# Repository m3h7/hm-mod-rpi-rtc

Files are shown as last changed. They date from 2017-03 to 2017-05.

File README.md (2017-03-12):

# hm-mod-rpi-rtc
Copyright (c) 2017 Maik Hinrichs  
**License**: [Creative Commons Attribution 4.0 International (CC BY-NC-SA 4.0)](https://creativecommons.org/licenses/by-nc-sa/4.0/).

Ergänzung des Homematic Funkmodules [hm-mod-rpi-pcb](https://www.elv.de/homematic-funkmodul-fuer-raspberry-pi-bausatz.html)
für den Raspberry Pi um eine Real Time Clock (RTC).

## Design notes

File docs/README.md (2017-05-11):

# hm-mod-rpi-rtc
## Schaltplan
[Schaltplan des Modules](hm-mod-rpi-rtc.pdf "Schaltplan")
## Bestückungsplan
- Vorderseite

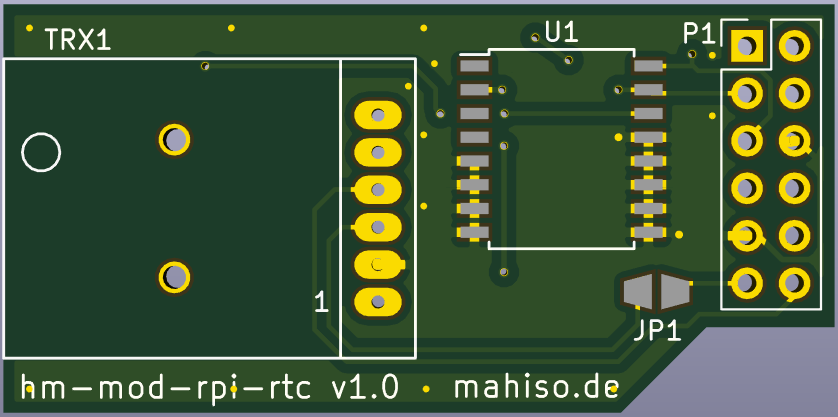
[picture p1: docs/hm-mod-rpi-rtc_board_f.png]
Bestückungsplan Vorderseite


- Rückseite

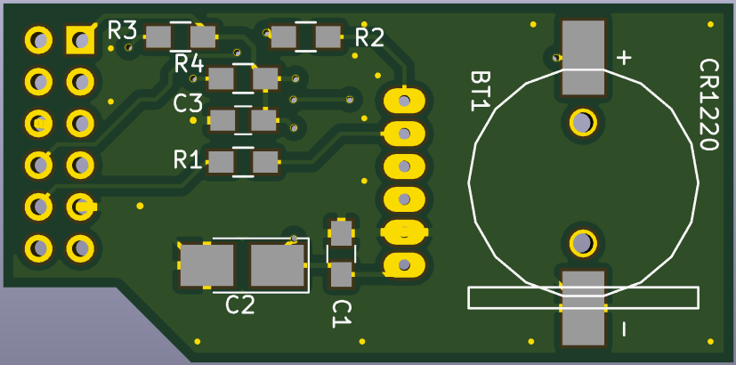
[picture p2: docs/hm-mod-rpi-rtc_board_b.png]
Bestückungsplan Rückseite


**Anmerkung**: Bestückungszeichnung der Batteriehalterung BT1 ist falsch. Eingesetzt (siehe untere Ansicht) ist die Halterung korrekt (Issue #3)

## Stückliste
|Bezeichnung|Wert / Bauform|Anmerkung|Reichelt Nr.|
|---|---|---|---|
|TRX1|HM-MOD-UART|aus ELV Bausatz|-|
|P1|Buchsenleiste 2x6|aus ELV Bausatz|-|
|U1|DS3231 / SOIC-16W ||DS 3231 S|
|R1,R2|1kΩ / 0805||RND 0805 1 1,0K
|R3,R4|4.7kΩ / 0805||RND 0805 1 4,7K|
|C1,C3|100nF / 0805||X7R-G0805 100N|
|C2|100µF/10V / Tantal B||TAJ 3528 100/10|
|BT1|Batteriehalter CR1220||-|
|CR1220|Batterie CR1220||CR 1220|

* Reichelt Bestellnummern ohne Garantie.

## Ansichten
- Bestückte Vorderseite

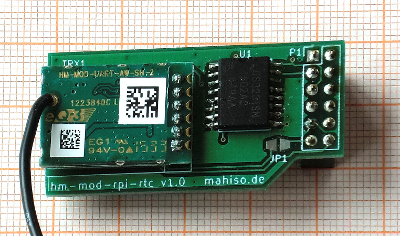
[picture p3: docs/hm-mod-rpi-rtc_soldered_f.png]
Bestückte Vorderseite

- Bestückte Rückseite

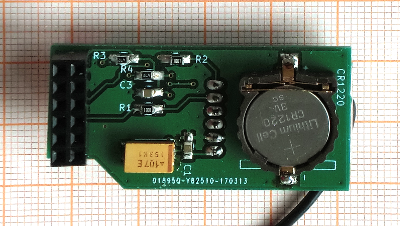
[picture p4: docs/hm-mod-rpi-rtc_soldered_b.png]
Bestückte Rückseite

- Eingesetzt in Raspberry Pi 2

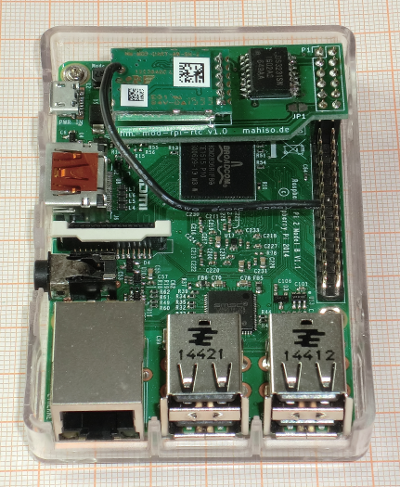
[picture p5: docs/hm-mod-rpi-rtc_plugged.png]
Eingesetzt in Raspberry Pi 2


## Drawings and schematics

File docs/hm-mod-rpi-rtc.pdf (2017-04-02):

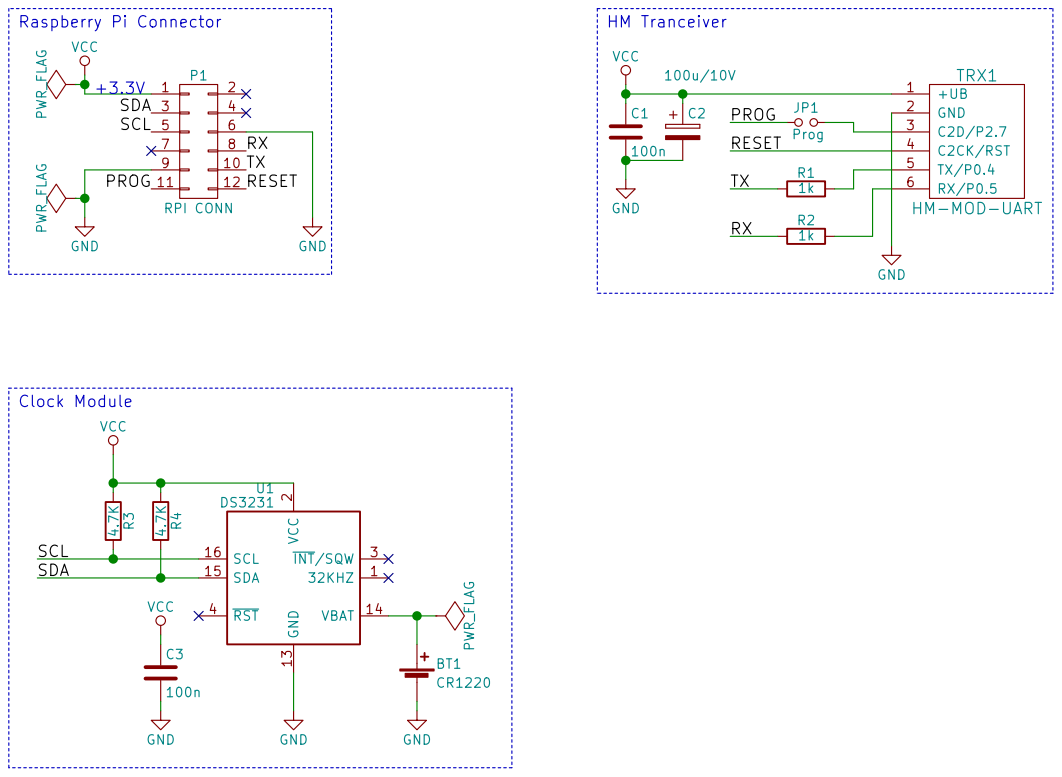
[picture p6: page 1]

File: hm-mod-rpi-rtc.sch Sheet: / M. Hinrichs

Id: 1/1 Title: HM-MOD-RPI-RTC

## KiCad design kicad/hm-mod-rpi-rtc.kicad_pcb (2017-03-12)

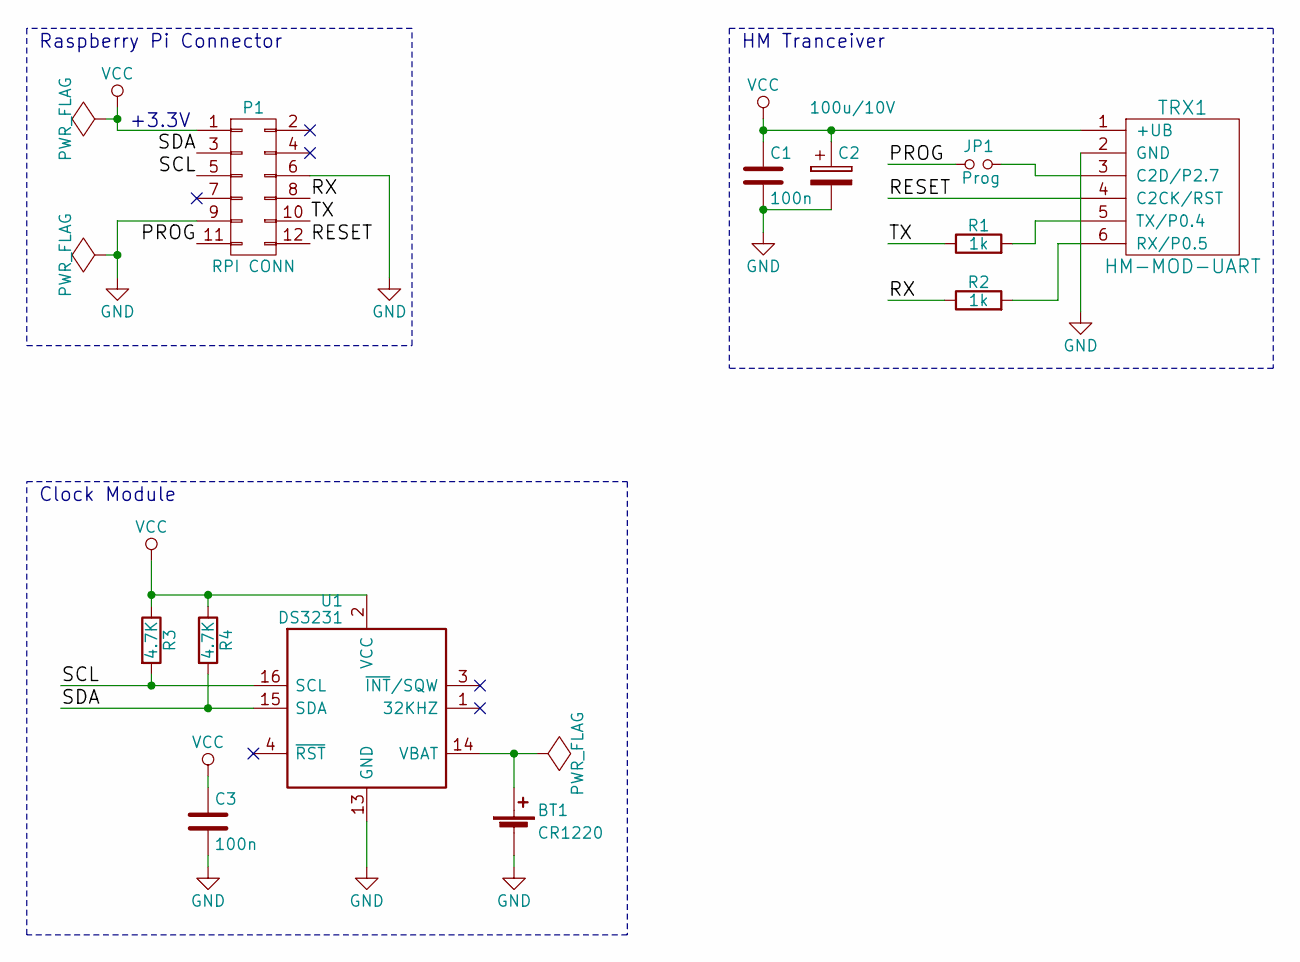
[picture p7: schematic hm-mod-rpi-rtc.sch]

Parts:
BT1: CR1220; CR1220_holder
C1, C3: 100n; C_0805_HandSoldering
C2: 100u/10V; CP_Tantalum_Case-B_EIA-3528-21_Hand
JP1: Prog; solder_jumper
P1: RPI CONN; Pin_Header_Straight_2x06_Pitch2.54mm
R1, R2: 1k; R_0805_HandSoldering
R3, R4: 4.7K; R_0805_HandSoldering
TRX1: HM-MOD-UART
U1: DS3231; SOIC-16W_7.5x10.3mm_Pitch1.27mm

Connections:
/PROG: JP1.1, P1.11
/RESET: P1.12, TRX1.4 (C2CK/RST)
/RX: P1.8, R2.1
/SCL: P1.5, R3.2, U1.16 (SCL)
/SDA: P1.3, R4.2, U1.15 (SDA)
/TX: P1.10, R1.1
GND: BT1.2 (-), C1.2, C2.2, C3.2, P1.6, P1.9, TRX1.2 (GND), U1.5 (NC), U1.6 (NC), U1.7 (NC), U1.8 (NC), U1.9 (NC), U1.10 (NC), U1.11 (NC), U1.12 (NC), U1.13 (GND)
unnamed: BT1.1 (+), U1.14 (VBAT)
unnamed: JP1.2, TRX1.3 (C2D/P2.7)
unnamed: R1.2, TRX1.5 (TX/P0.4)
unnamed: R2.2, TRX1.6 (RX/P0.5)
VCC: C1.1, C2.1, C3.1, P1.1, R3.1, R4.1, TRX1.1 (+UB), U1.2 (VCC)

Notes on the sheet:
+3.3V
Raspberry Pi Connector
HM Tranceiver
Clock Module

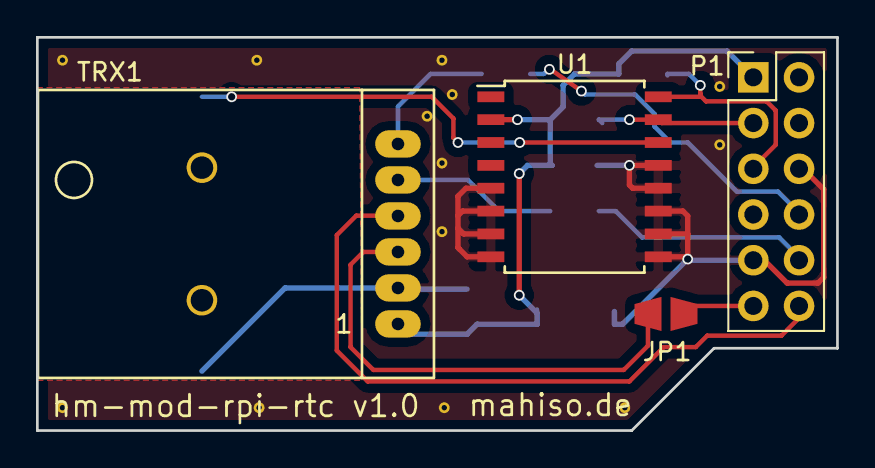
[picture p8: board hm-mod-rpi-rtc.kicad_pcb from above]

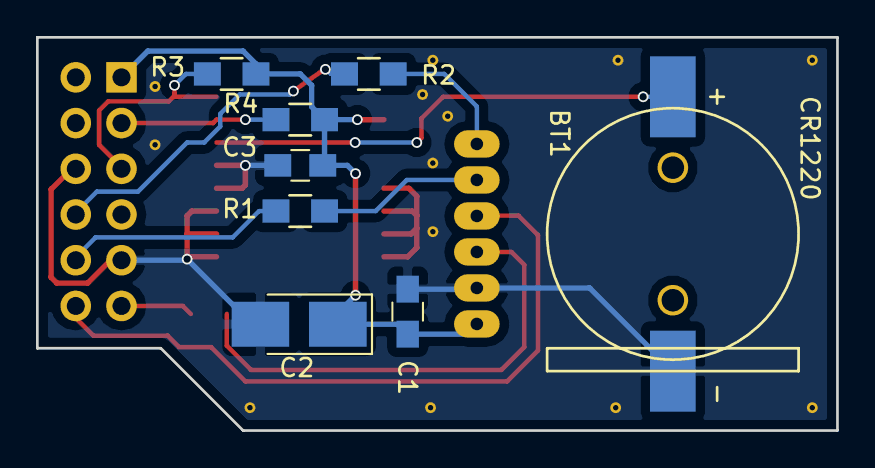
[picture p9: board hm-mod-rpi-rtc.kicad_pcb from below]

Board: 2 copper layers, 44.5 x 21.8 mm, 12 parts (8 on the bottom side), 12 nets.

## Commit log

2017-02-08 Initial: HM-MOD-UART + DC3231
    [hm-mod-rpi-rtc.kicad_pcb, hm-mod-rpi-rtc.sch]
2017-04-02 Add sheet and board printouts
2017-04-02 Board printout fixed
2017-04-09 Dokumentation: Readme und Fotos hinzugefügt.
